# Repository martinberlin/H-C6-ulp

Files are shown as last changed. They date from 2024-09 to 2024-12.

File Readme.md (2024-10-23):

### ESP32-C6 ULP mini PCB

This PCB design is based on [C6 design guidelines](https://docs.espressif.com/projects/esp-hardware-design-guidelines/en/latest/esp32c6/schematic-checklist.html) and uses the Buck converter schematic of Seeed XIAO C6 [SGM6029](https://www.sg-micro.com/product/SGM6029)

> The SGM6029 family is a low voltage, efficient and miniature synchronous Buck converter with ultra-low quiescent current. Operating at high switching frequency (4.0MHz, TYP), miniature inductors and capacitors can be used to achieve minimal solution size.

#### Using low GPIOs to be able to access them from ULP

```
IO Description
0 EPD_MOSI
1 EPD_CLK
2 EPD_CS
3 EPD_DC
4 EPD_BSY
5 EPD_RST
6 SCL --> I2C ↘
7 SDA --> I2C connected to RV2032 RTC
```

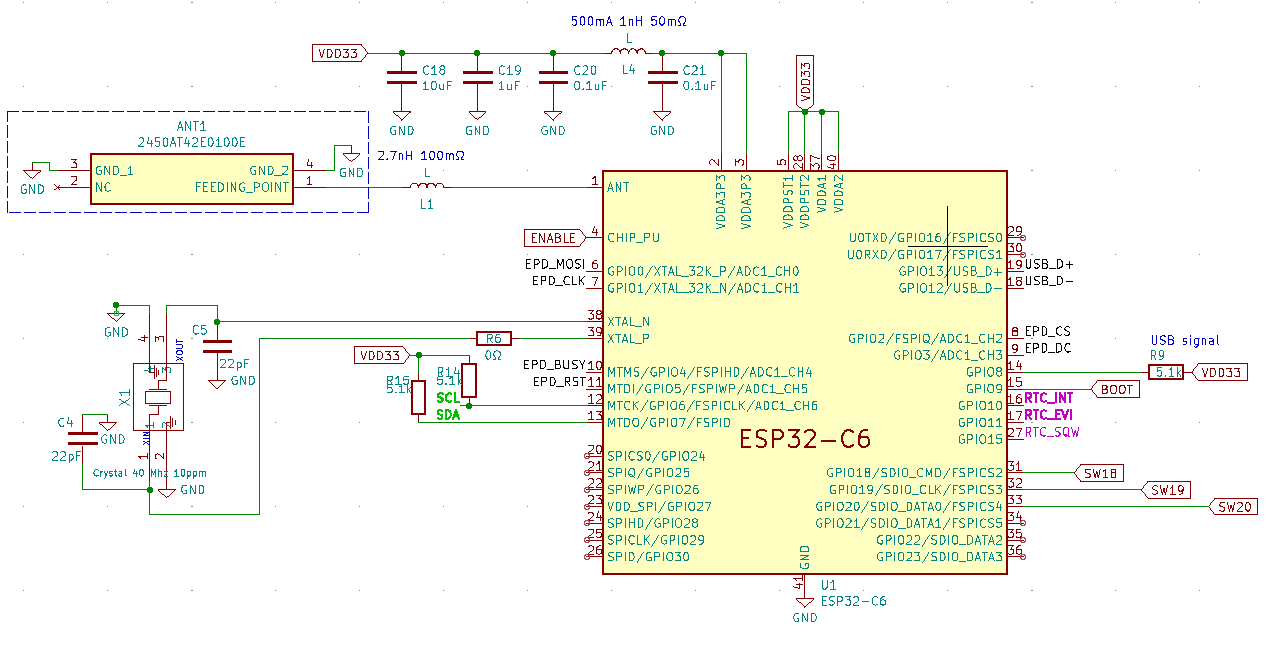
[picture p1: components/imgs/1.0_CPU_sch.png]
CPU schematic


### Push buttons GPIOs (optional side switches)

```
IO Description
19 Left  SW1 
20 Right SW2
18 Right SW3
```

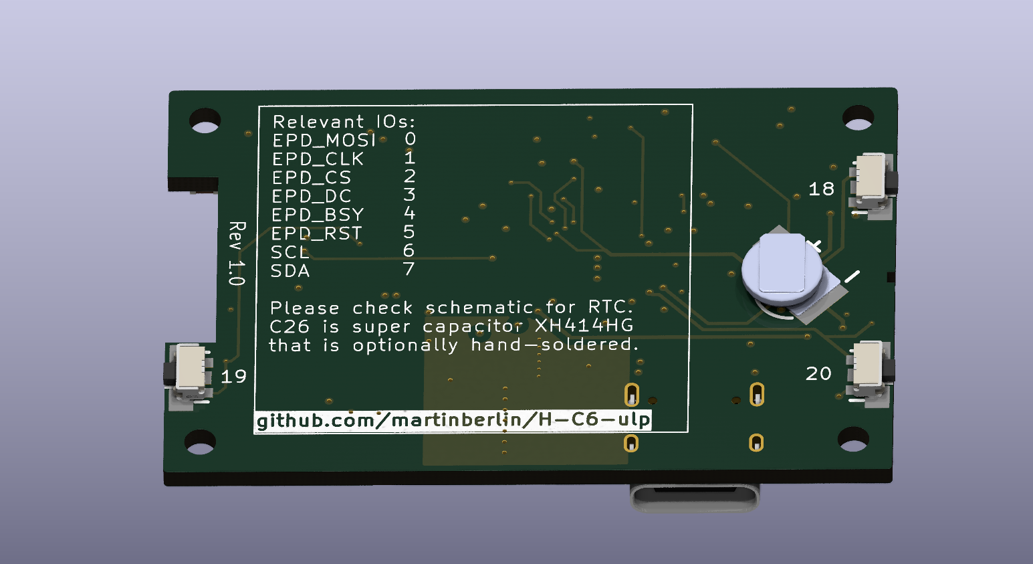
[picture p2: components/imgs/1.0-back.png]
SW placement


### 3D-Preview

Last version 1.1:

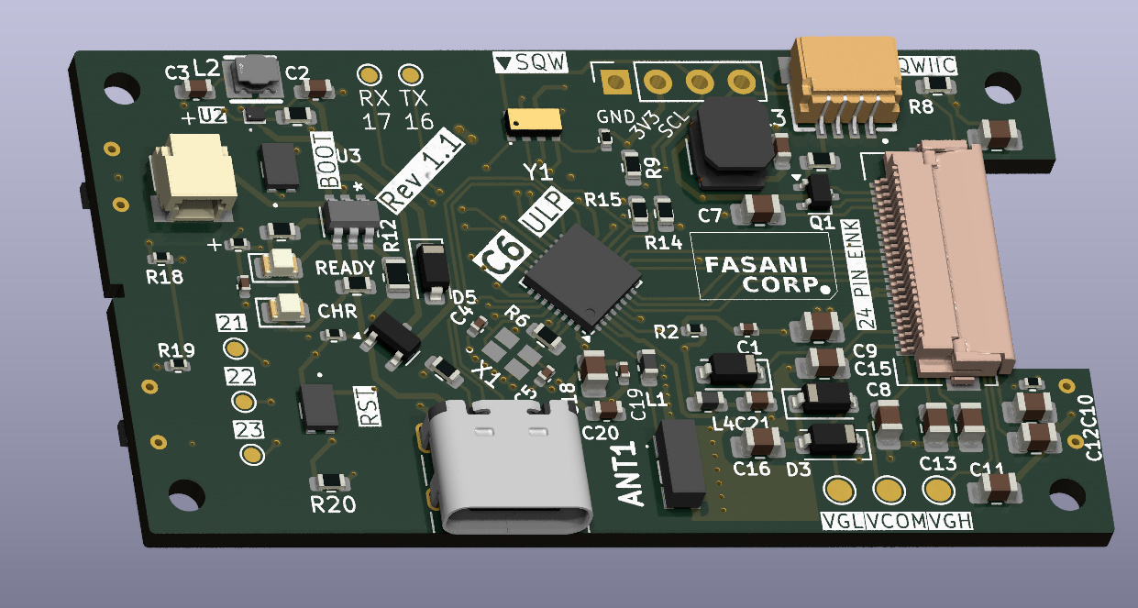
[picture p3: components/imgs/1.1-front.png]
Front PCB preview


Failed release v1.0: We forgot to add SPI flash. Oh yeah, you won't flash it!
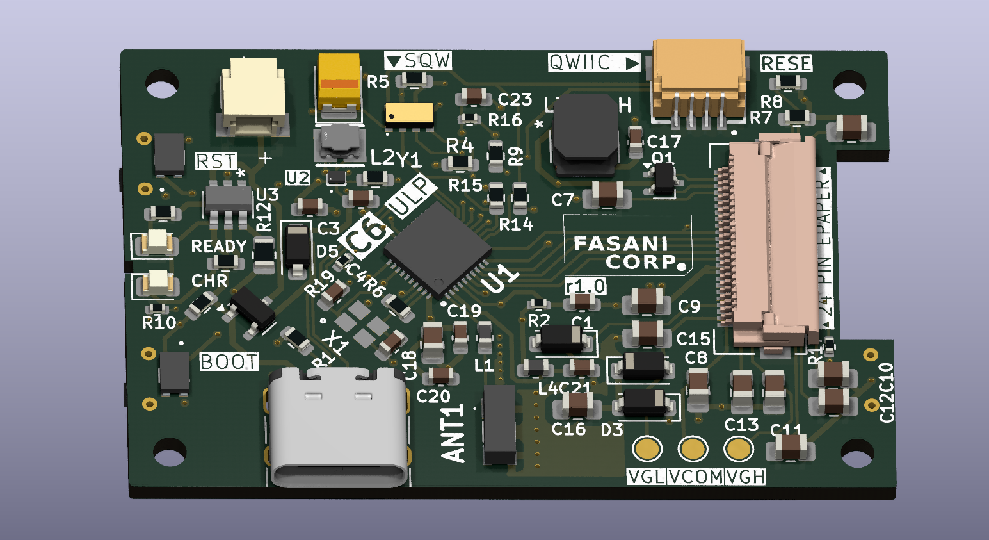
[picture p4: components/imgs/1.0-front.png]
Front PCB preview


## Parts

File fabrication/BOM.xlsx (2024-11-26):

Designator | Footprint | Comment | JLCPCB Part #
C14,C11,C6,C7,C15,C13 | C_0805_2012Metric_Pad1.18x1.45mm_HandSolder | 4.7uF | C1779
D5 | D_SOD-123 | 1N5817 | C8598
R17,R2,R18,R19,R16,R7,R4,R10 | R_0402_1005Metric | 10k | C25804
C1,C19 | C_0402_1005Metric | 1uF | C162161
C2,C3 | C_0603_1608Metric | 10 uF | C6119874
C5,C23,C4 | C_0402_1005Metric | 22pF | C5119318
R6 | R_0603_1608Metric | 0Ω | C21189
D2,D1,D3 | D_SOD-123 | MBR0530 | C77336
U3 | TP4057-42-SOT26-R | TP4057-42-SOT26-R | C12044
L2 | IND-SMD_L2.5-W2.0_SPH252012 | 0.47 uH | C329586
L3 | SWPA4030S1R0NT | 10uH | C38117
C8,C9,C10,C12 | C_0805_2012Metric_Pad1.18x1.45mm_HandSolder | 1uF | C28323
J3 | SM02BSRSSTBLFSN | SM02B-SRSS-TB(LF)(SN) | C160402
L1,L4 | L_0603_1608Metric | L | C5252358
R15,R20,R14,R13,R1,R9,R11 | R_0603_1608Metric | 5.1k | C23186
C20,C21 | C_0603_1608Metric | 0.1uF | C327087
SW2,SW1 | switch_SKSVCCE010 | SW_Push_Dual | C325005
C16 | C_0805_2012Metric_Pad1.18x1.45mm_HandSolder | 4.7uF 50V | C1779
C18 | C_0805_2012Metric | 10uF | C15850
C17 | C_0603_1608Metric | 4.7uF | C19666
R3 | R_0603_1608Metric | 249k 1% | C6945215
X1 | Crystal_ECS-40Mhz_ECS | Crystal 40 Mhz 10ppm | C555614
R12 | R_0805_2012Metric | 2K2 | C17520
J1 | USB_C_Receptacle_HRO_TYPE-C-31-M-12 | USB_C_Receptacle_USB2.0 | C165948
ANT1 | 2450AT42E0100E-ANT | 2450AT42E0100E | C3285081
Y1 | RV3032C7 | RV-3032-C7 | C5127802
D6 | LED_0805_2012Metric | GRE | C2297
J2 | AFC24-S24FIC-00 | AFC24-S24FIC-00 | C262292
R8 | R_0603_1608Metric | 0.47R | C103895
U2 | SGM6029_WLCSP-6 | SGM6029CYG/TR | C5153500
Q2 | SOT-23 | Si2301CDS | C10487
U1 | QFN-32-1EP_5x5mm_P0.5mm_EP3.6x3.6mm | ESP32-C6FH4 | C6908287
Q1 | SOT-323_SC-70 | Si1308 | C4322213
D4 | LED_0805_2012Metric | RED | C84256
J4 | QWIIC_SM04B-SRSS-TB_LFSN_ | SM04B-SRSS-TB_LF__SN_ | C160404

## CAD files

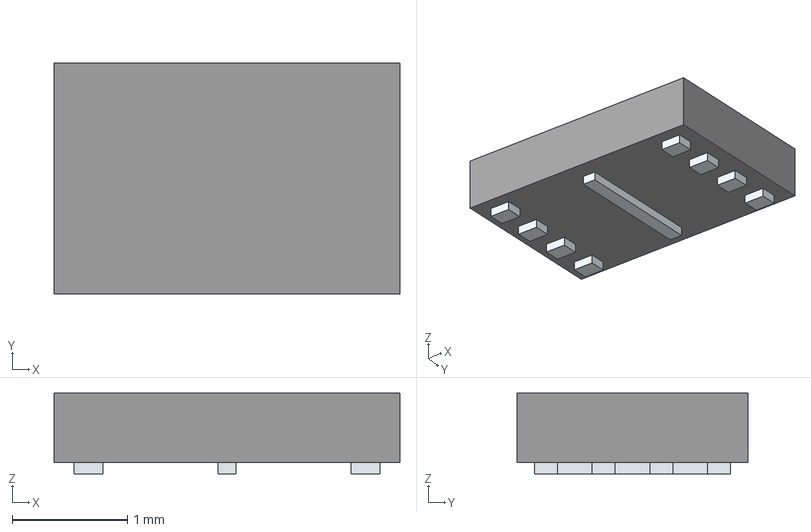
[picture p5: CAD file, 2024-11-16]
C6-40-Flash-test/components/3d/MX25R1635FZUIL0_TR_Flash.stp
3.00 x 2.00 x 0.7 mm
Pins

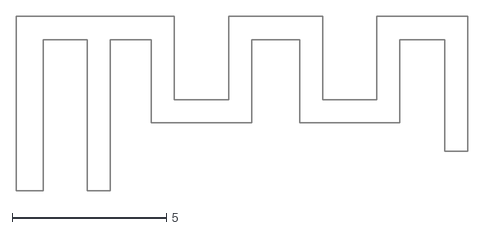
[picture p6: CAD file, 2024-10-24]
C6-40-Flash-test/components/ANTENNA - MIFA_TYPEB.dxf
14.6 x 5.65

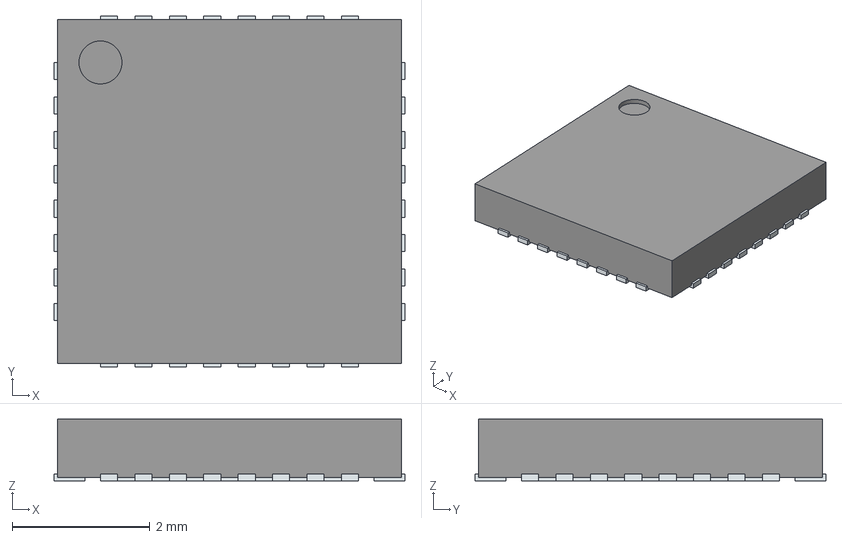
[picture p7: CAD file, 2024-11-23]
components/3D/ESP32-C6FH4.stp
5.10 x 5.10 x 0.9 mm
ThermalPin
PinsArrayLR
PinsArrayTB

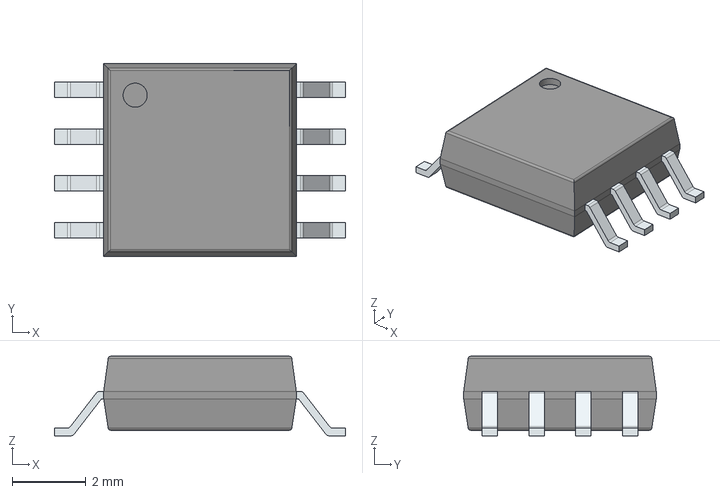
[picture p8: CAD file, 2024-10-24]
C6-40-Flash-test/components/3d/W25Q128JVSIQ-winbond-flash.stp
7.90 x 5.23 x 2.16 mm
PinsArrayLR

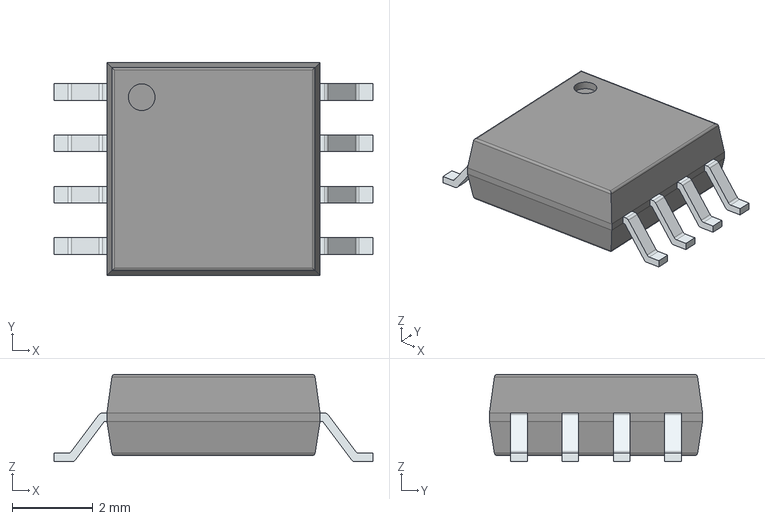
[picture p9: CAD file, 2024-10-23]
components/3D/W25Q80DVSSIG_FLASH.stp
7.90 x 5.28 x 2.16 mm
PinsArrayLR

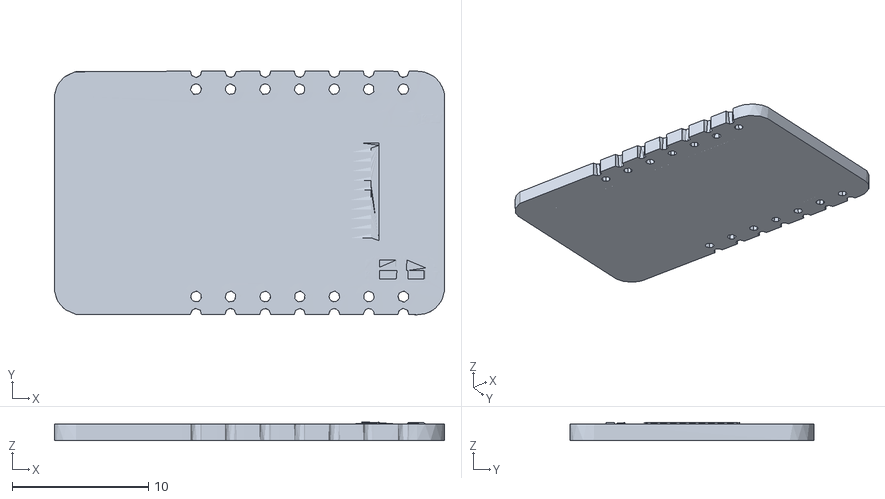
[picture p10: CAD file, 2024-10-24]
C6-40-Flash-test/components/3d/xiao-clean.stl
28.7 x 17.9 x 1.33

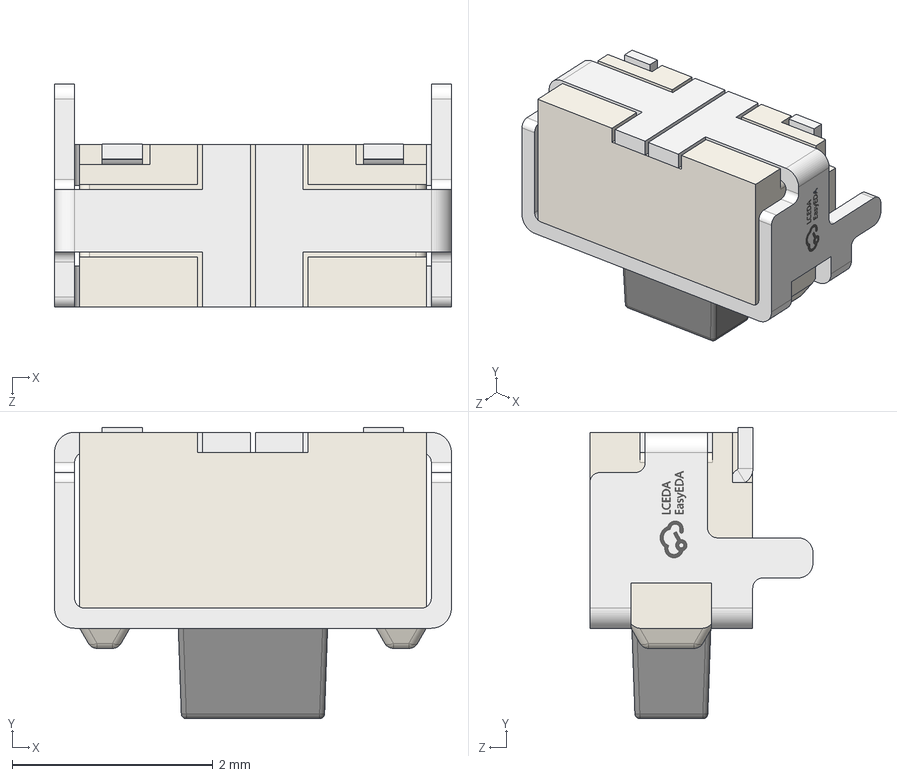
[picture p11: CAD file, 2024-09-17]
components/3D/KEY-SMD_L4.0-W2.9-H1.6-P3.75.step
3.95 x 2.90 x 2.22 mm

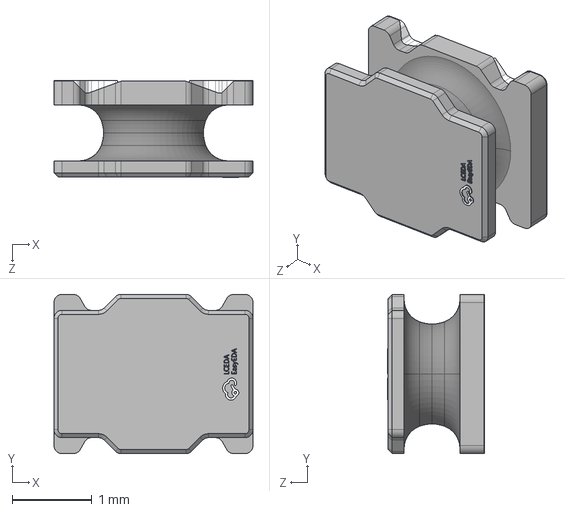
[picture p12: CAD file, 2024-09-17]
components/3D/IND-SMD_L2.5-W2.0-H1.2_SPH252012.step
2.50 x 2.00 x 1.22 mm

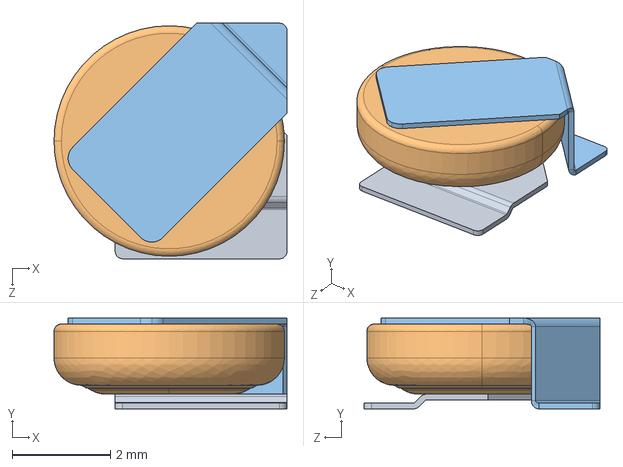
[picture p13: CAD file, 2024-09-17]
components/3D/SuperCAP_XH414HG-IV01E.stp
4.75 x 1.85 x 4.80 mm

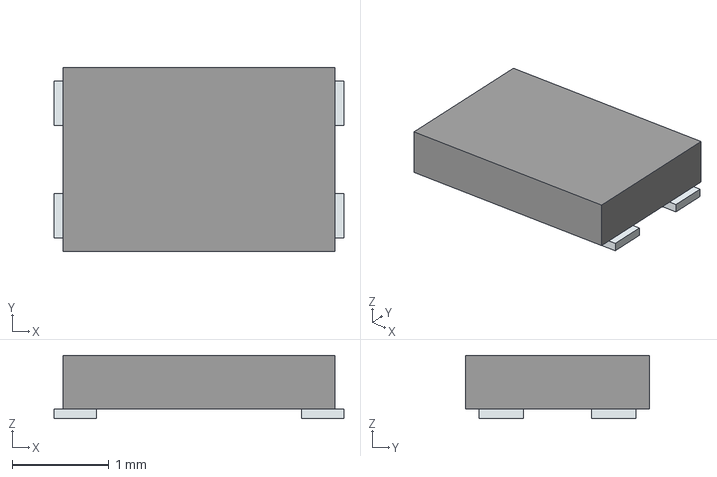
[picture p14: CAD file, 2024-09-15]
components/3D/switch_SKSVCCE010.stp
2.99 x 1.90 x 0.65 mm
Pins

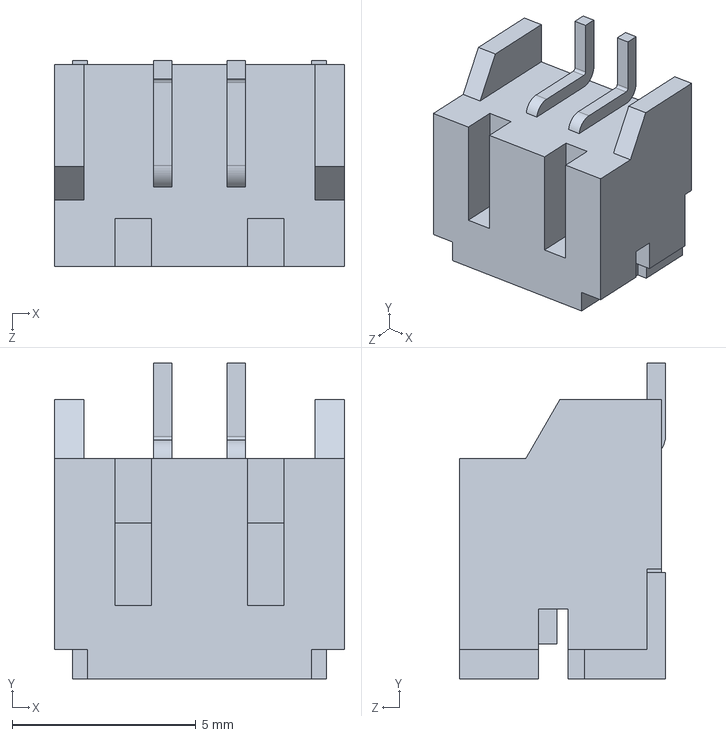
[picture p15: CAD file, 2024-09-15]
components/3D/S2B-PH-SM4-TB_LF__SN_.stp
7.90 x 8.60 x 5.60 mm

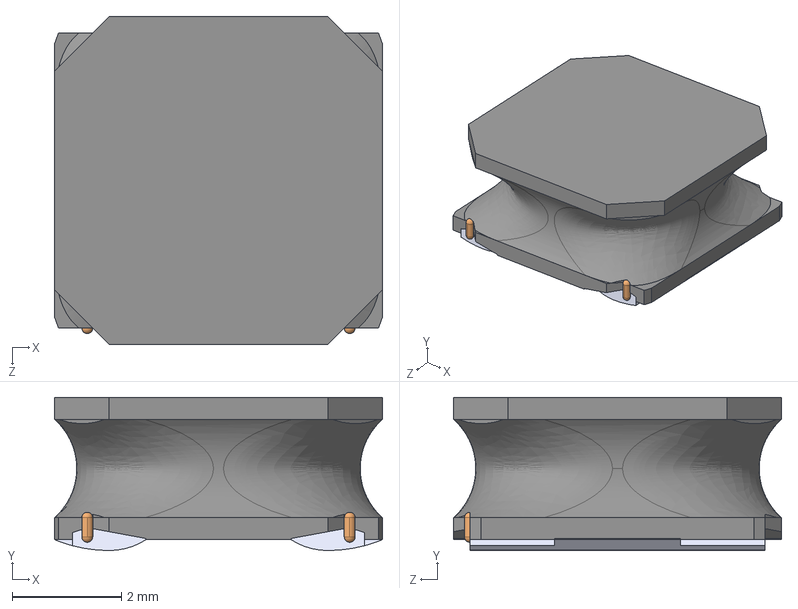
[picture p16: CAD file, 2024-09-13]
components/3D/L-40xx.stp
6.00 x 2.80 x 6.00 mm

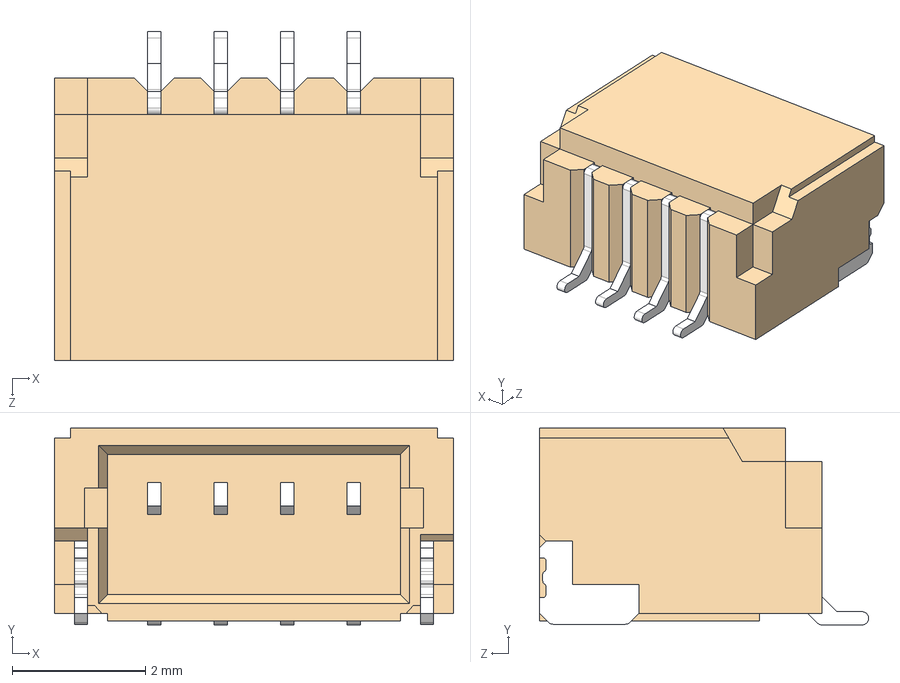
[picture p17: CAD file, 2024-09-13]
components/3D/QWIIC_SM04B-SRSS-TB_LF__SN_.stp
6.00 x 2.96 x 4.95 mm

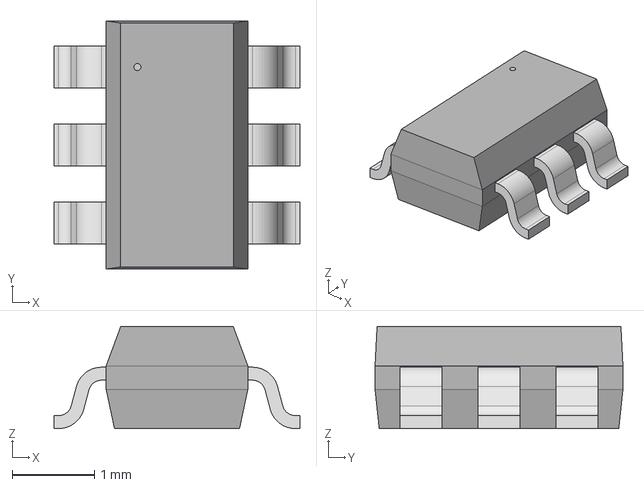
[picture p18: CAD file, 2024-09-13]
components/3D/TP4057-SOT-23.step
3.00 x 3.02 x 1.25 mm

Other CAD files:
components/3D/JST_SM02B-SRSS-TB__LF__SN.stp
components/3D/RV-3032-C7.stp
components/3D/FH12-24S-0.5SH_55_.step
components/3D/2450AT42E0100E-ANT.stp
components/3D/Crytal_ECS-40Mhz_ECS.step
components/3D/ESP32-C6.stp
components/3D/SGM6029_WLCSP-6_L1.0-W0.7.step
components/3D/USB_TYPE-C-31-M-12.step

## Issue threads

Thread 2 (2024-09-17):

PCB sharp Corners in layout

Uspizig, 2024-09-17:
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
Please avoid such sharp edges in PCB. This will result in underfill.

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

martinberlin, 2024-09-17:
Spider legs now look nicer
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
If you like the PCB project and it works will send you one as a present

Closed 2024-09-17.

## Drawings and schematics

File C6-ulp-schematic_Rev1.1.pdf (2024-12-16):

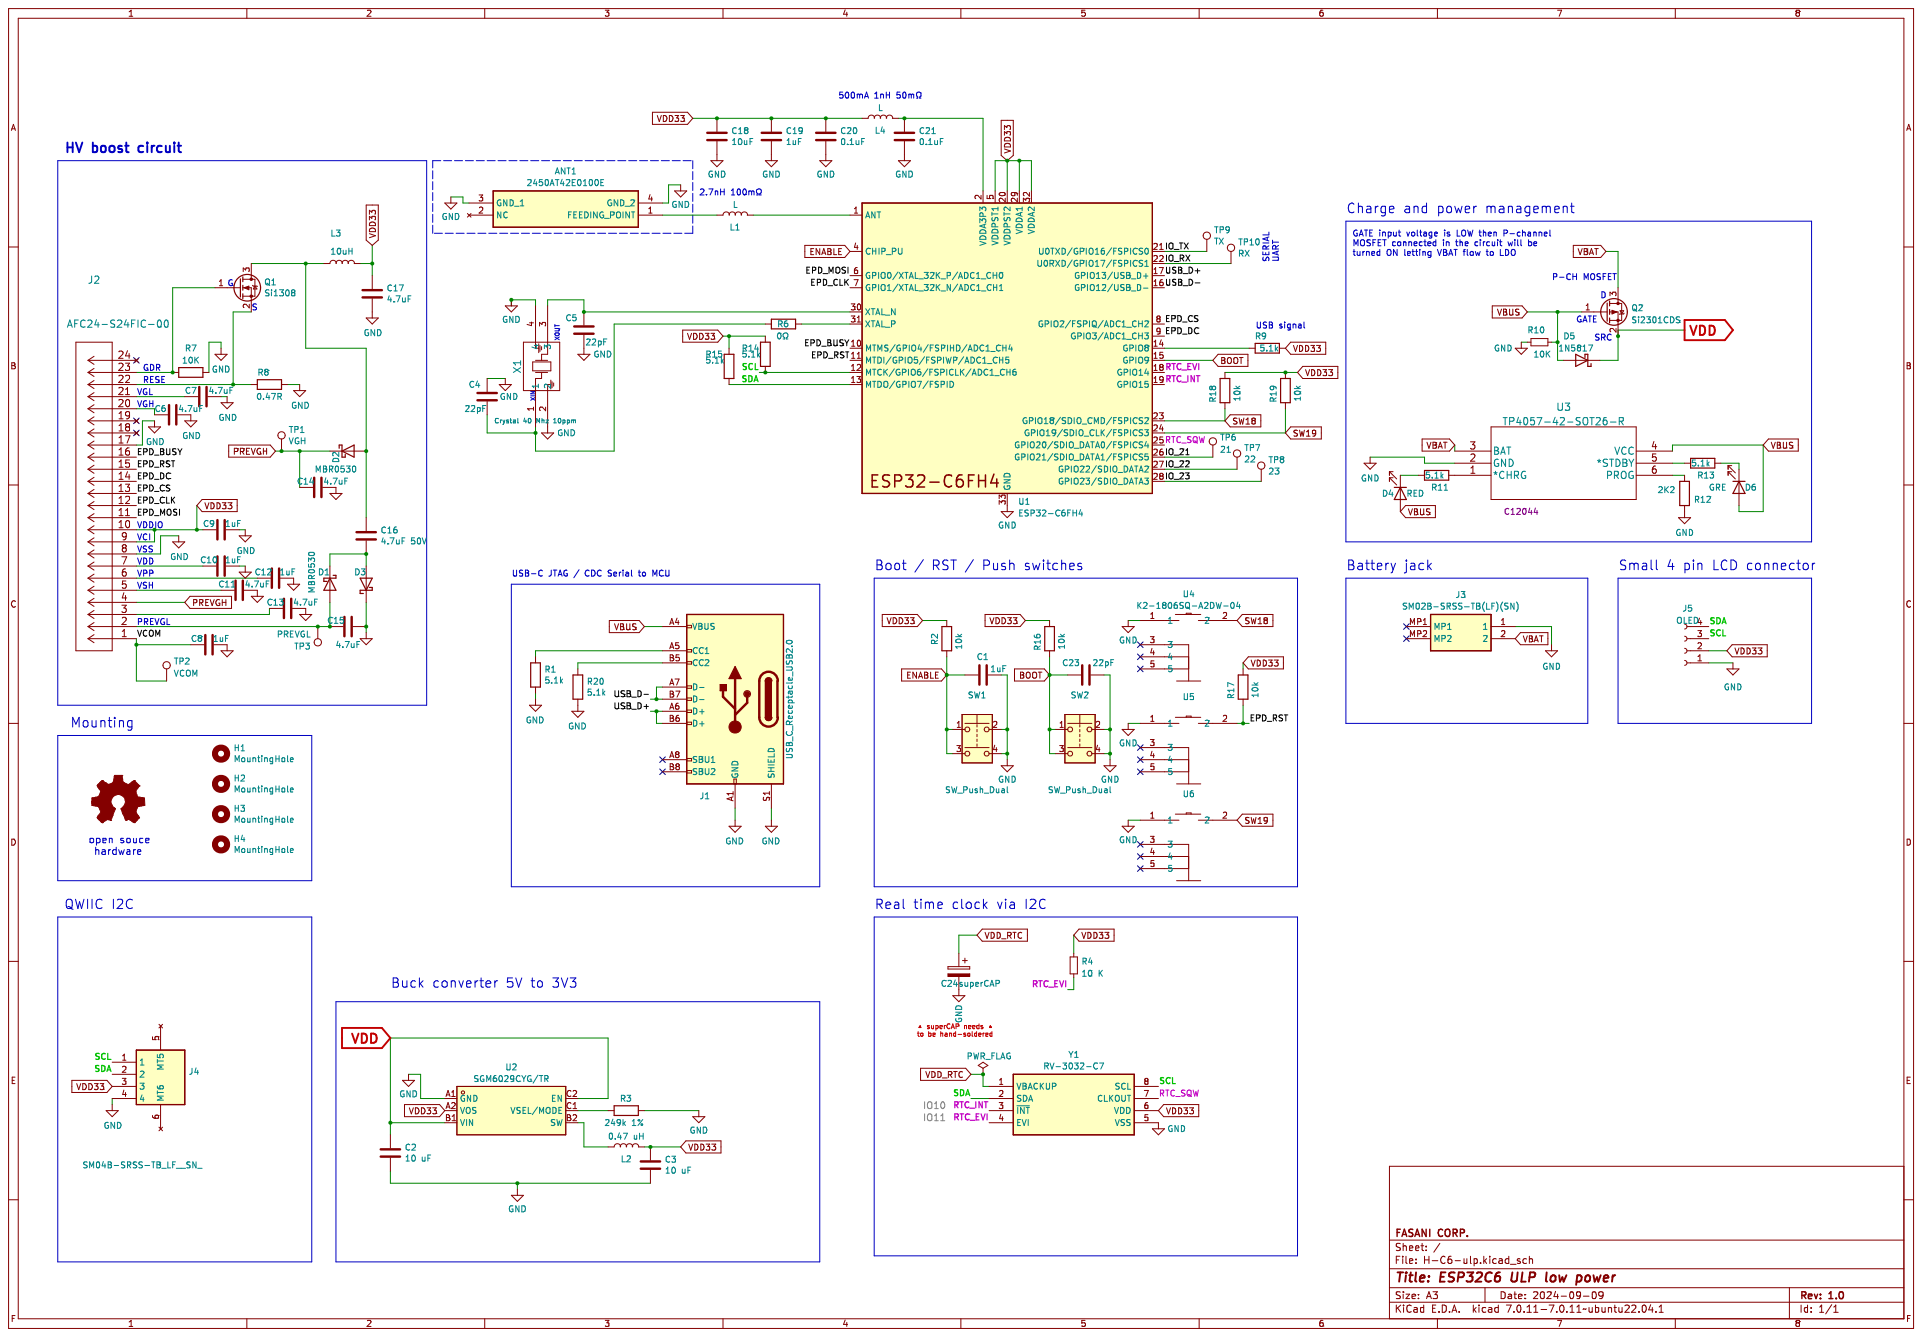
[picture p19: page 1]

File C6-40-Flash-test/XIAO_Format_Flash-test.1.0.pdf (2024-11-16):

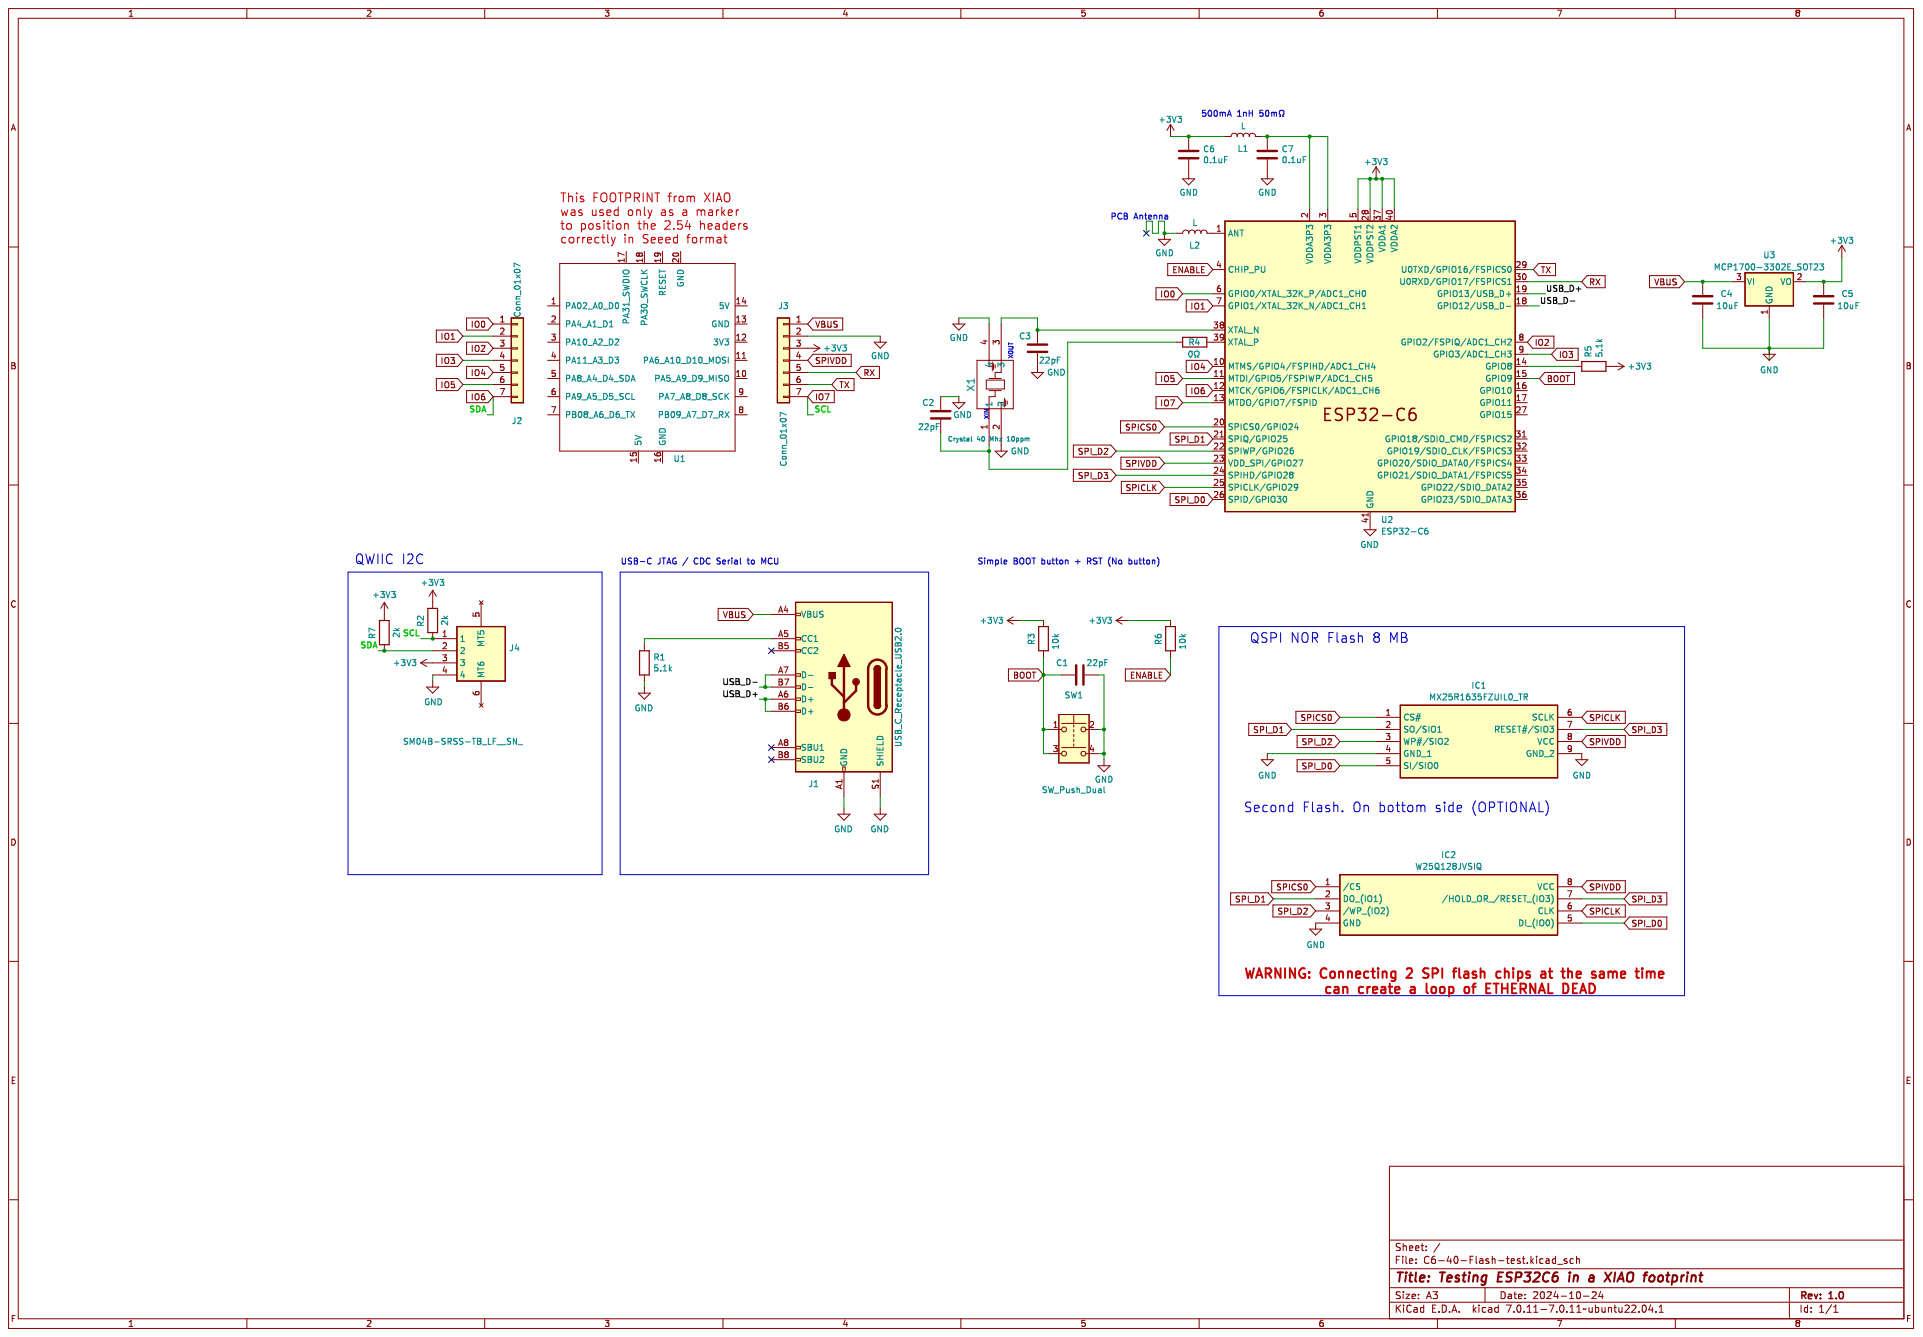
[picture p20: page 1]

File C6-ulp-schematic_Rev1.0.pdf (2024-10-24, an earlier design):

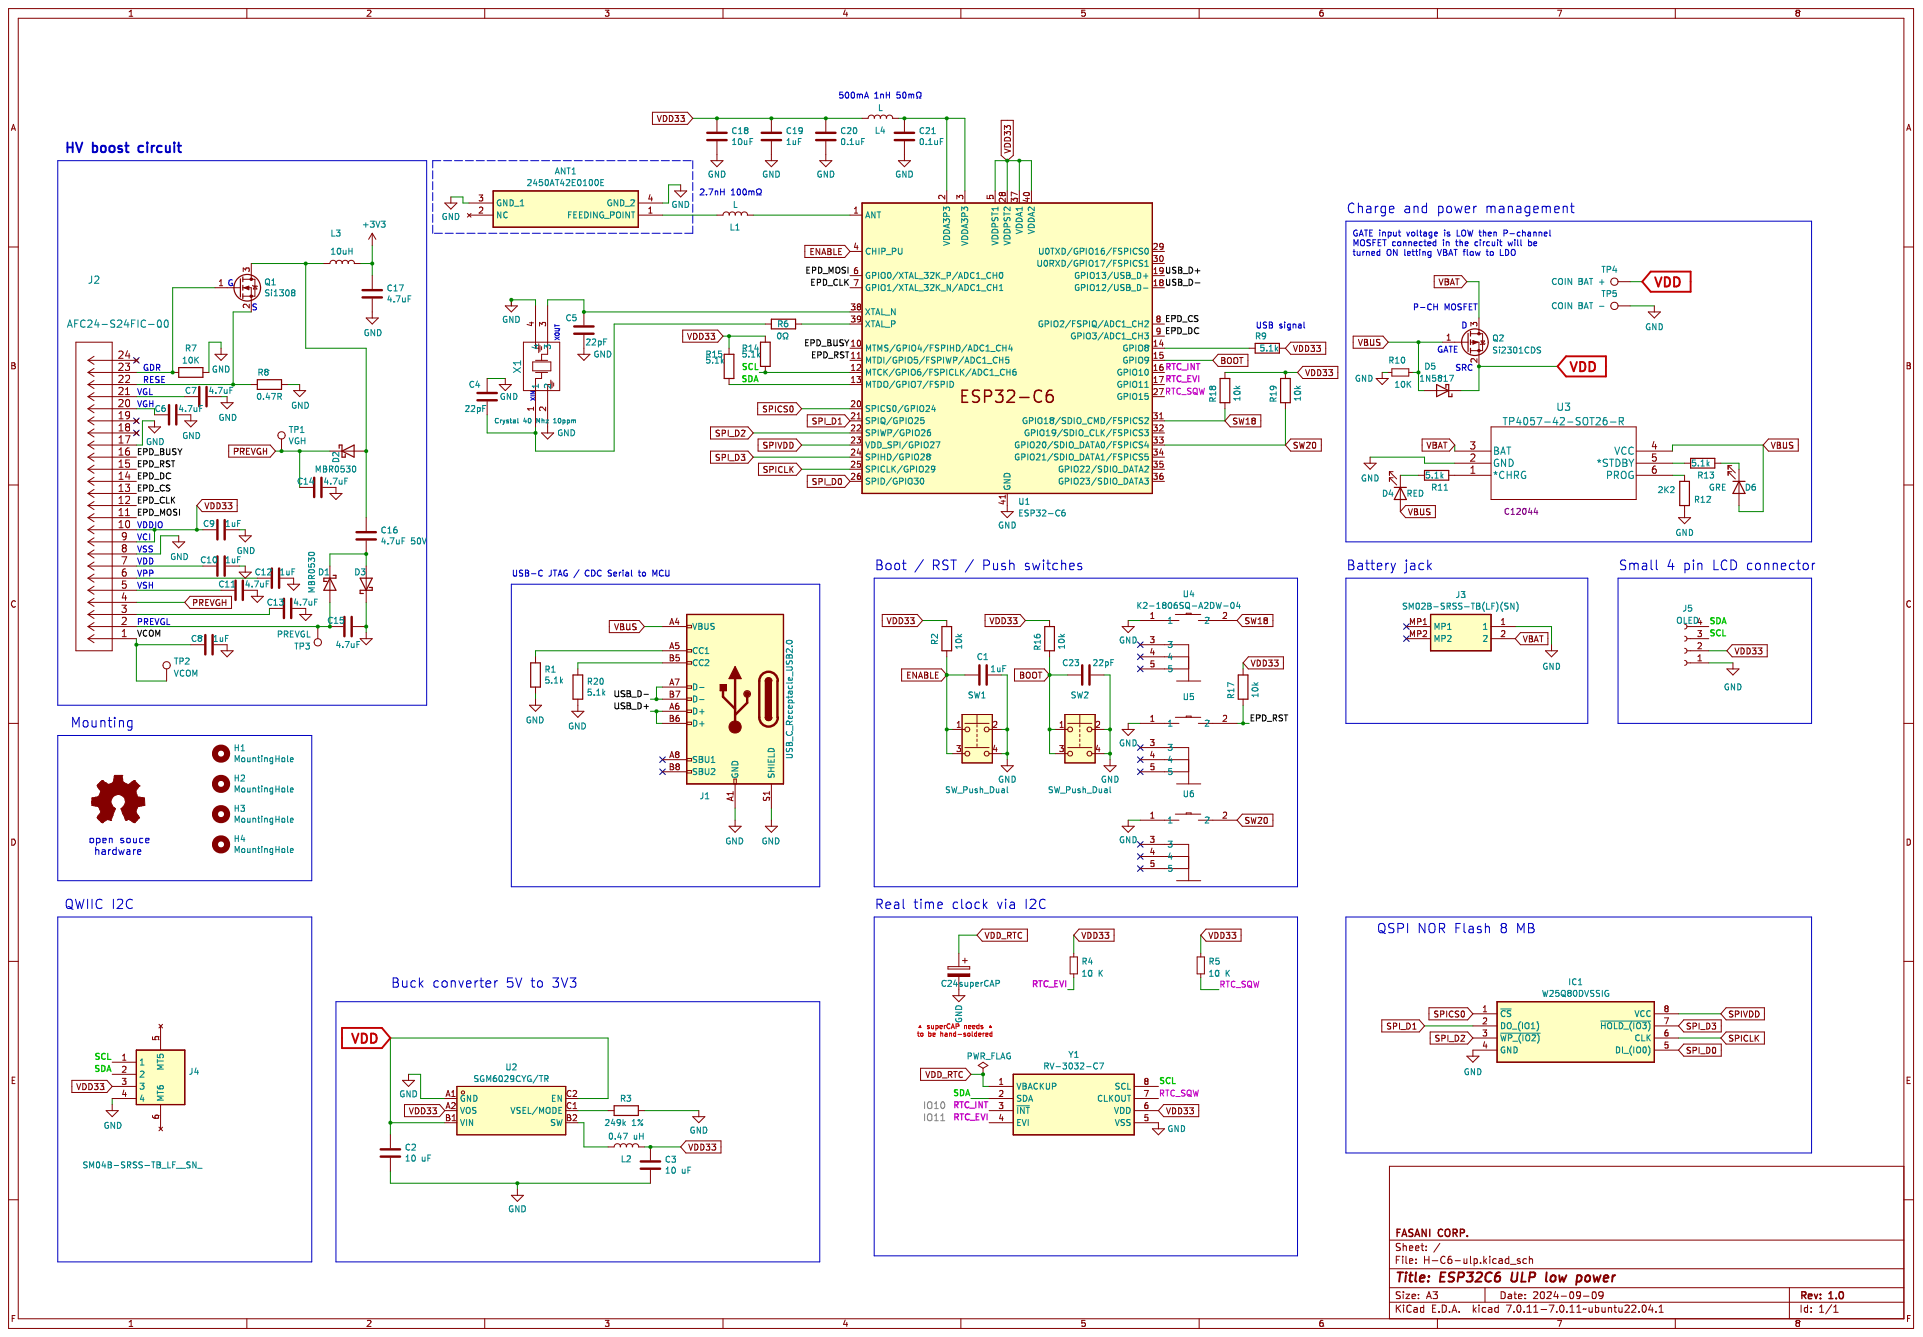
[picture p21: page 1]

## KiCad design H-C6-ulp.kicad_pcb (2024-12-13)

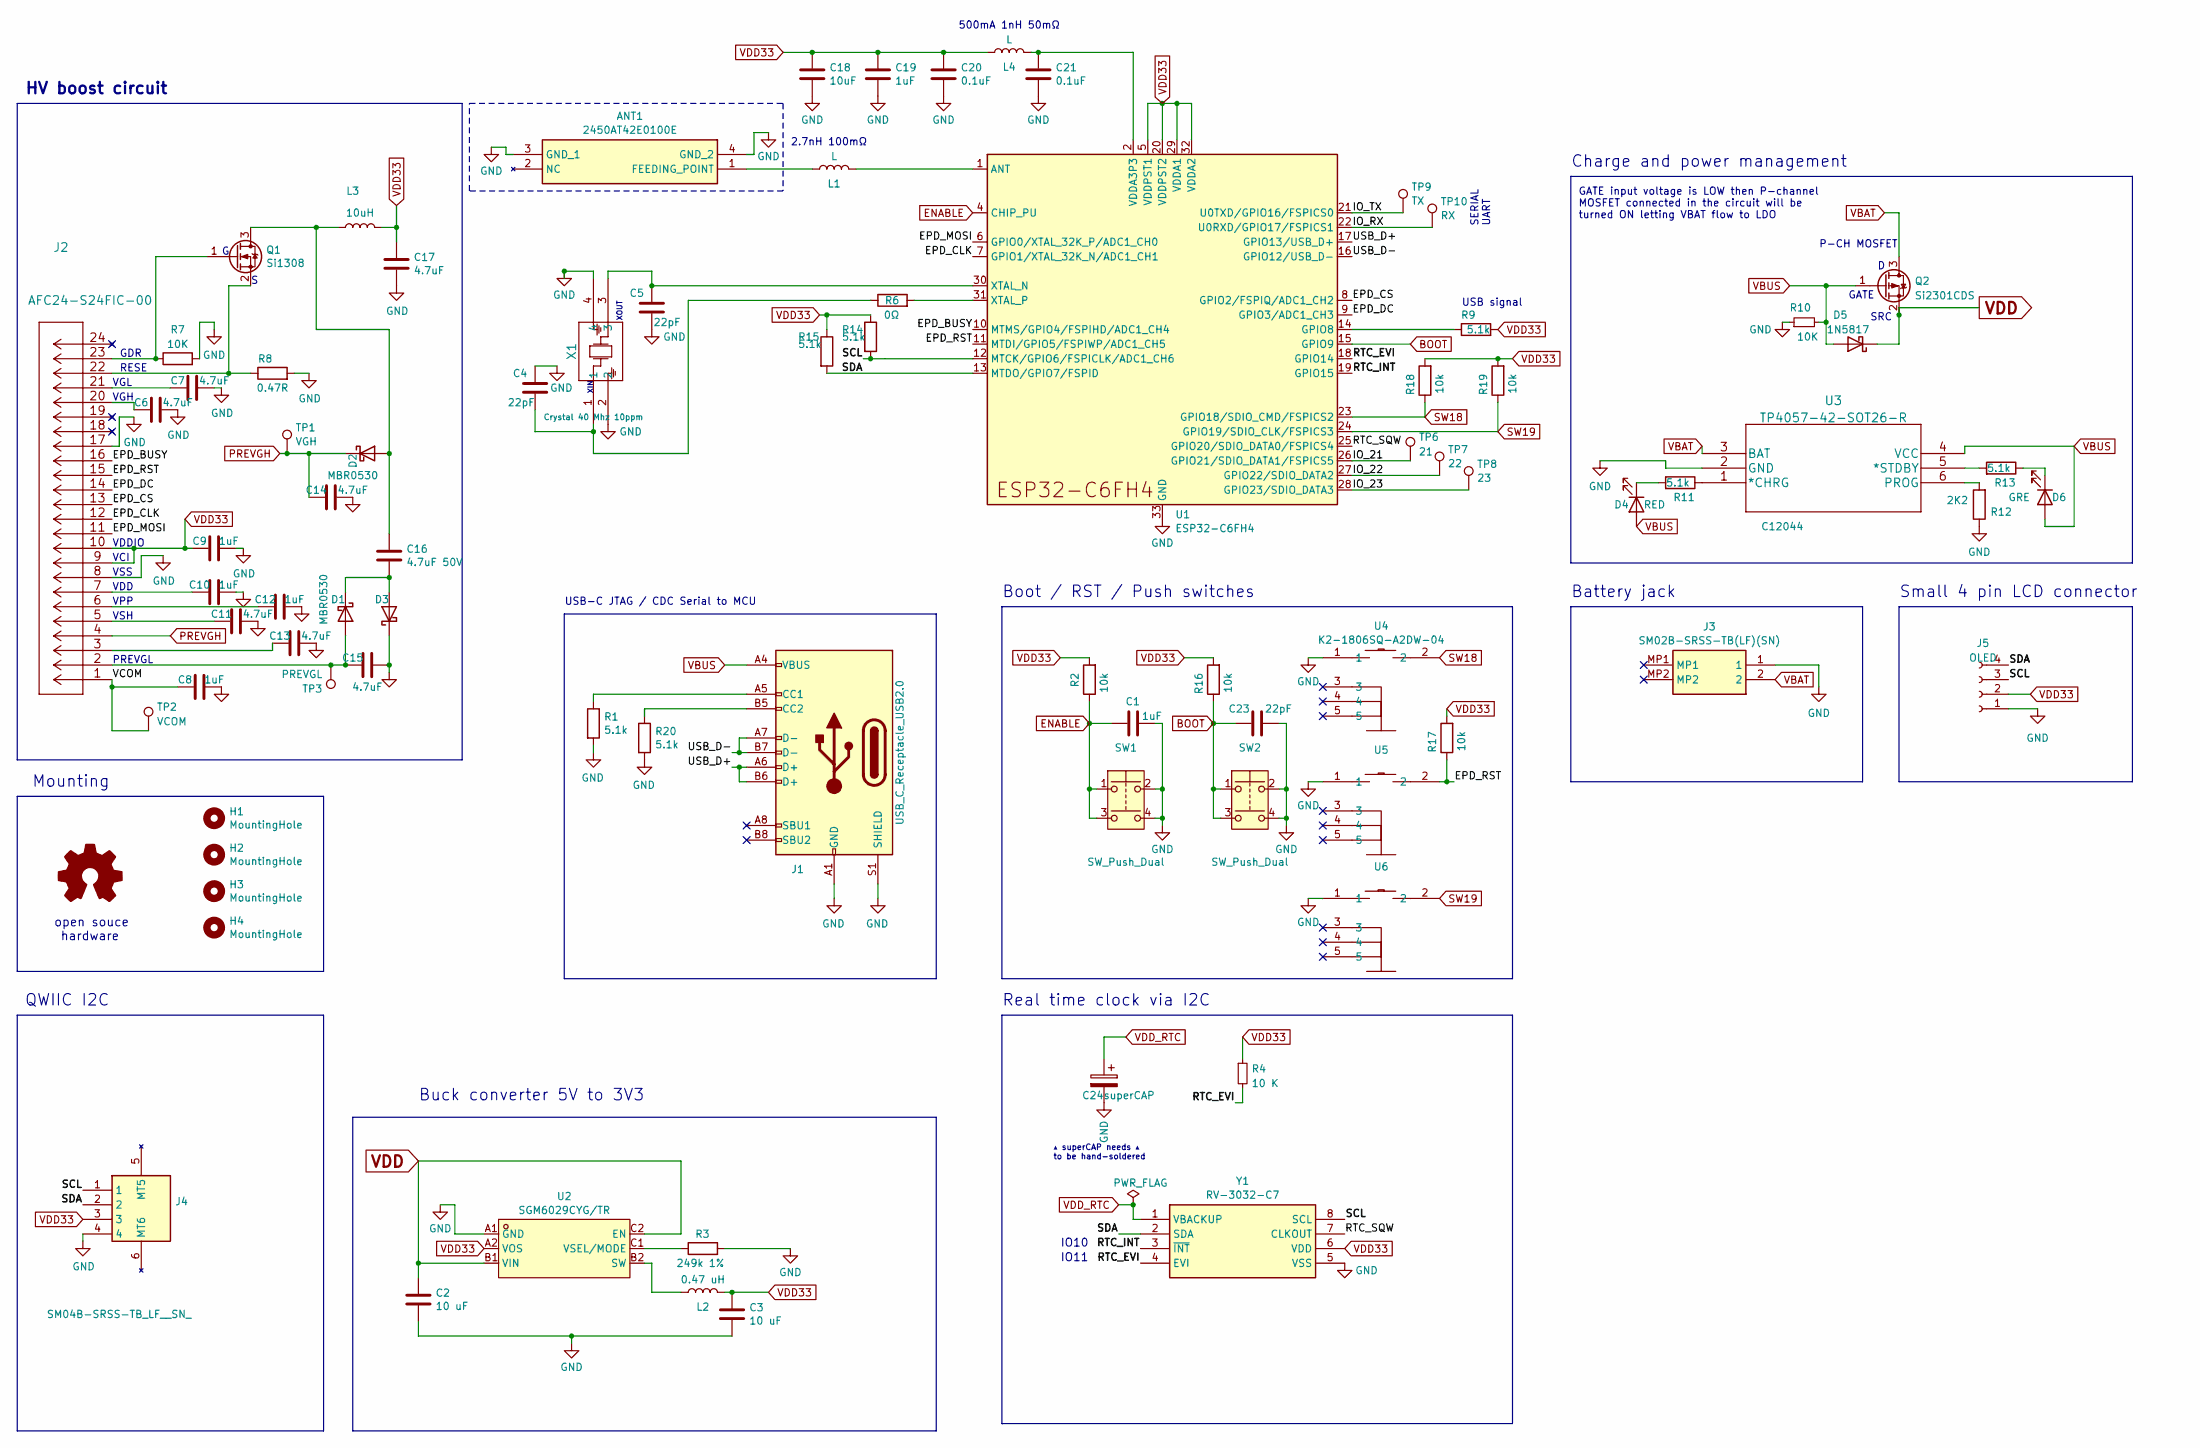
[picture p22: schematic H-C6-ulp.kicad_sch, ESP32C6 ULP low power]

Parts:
ANT1: 2450AT42E0100E; 2450AT42E0100E-ANT; LCSC C3285081
C1, C19: 1uF; C_0402_1005Metric; LCSC C162161
C2, C3: 10 uF; C_0603_1608Metric; LCSC C6119874
C4, C5, C23: 22pF; C_0402_1005Metric; LCSC C5119318
C6, C7, C11, C13, C14, C15: 4.7uF; C_0805_2012Metric_Pad1.18x1.45mm_HandSolder; LCSC C1779
C8, C9, C10, C12: 1uF; C_0805_2012Metric_Pad1.18x1.45mm_HandSolder; LCSC C28323
C16: 4.7uF 50V; C_0805_2012Metric_Pad1.18x1.45mm_HandSolder; LCSC C1779
C17: 4.7uF; C_0603_1608Metric; LCSC C19666
C18: 10uF; C_0805_2012Metric; LCSC C15850
C20, C21: 0.1uF; C_0603_1608Metric; LCSC C327087
C24: superCAP; superCAP-XH414HG; LCSC C129289
D1, D2, D3: MBR0530; D_SOD-123; LCSC C77336
D4: RED; LED_0805_2012Metric; LCSC C84256
D5: 1N5817; D_SOD-123; LCSC C8598
D6: GRE; LED_0805_2012Metric; LCSC C2297
H1, H2, H3, H4: MountingHole; MountingHole_2.2mm_M2
J1: USB_C_Receptacle_USB2.0; USB_C_Receptacle_HRO_TYPE-C-31-M-12; LCSC C165948
J2: AFC24-S24FIC-00; LCSC C262292
J3: SM02B-SRSS-TB(LF)(SN); SM02BSRSSTBLFSN; Manufacturer_Part_Number SM02B-SRSS-TB(LF)(SN); LCSC C160402
J4: SM04B-SRSS-TB_LF__SN_; QWIIC_SM04B-SRSS-TB_LFSN_; Manufacturer_Part_Number SM04B-SRSS-TB(LF)(SN); LCSC C160404
J5: OLED; PinSocket_1x04_P2.54mm_Vertical
L1: L; L_0603_1608Metric; LCSC C5252358
L2: 0.47 uH; IND-SMD_L2.5-W2.0_SPH252012; LCSC C329586
L3: 10uH; SWPA4030S1R0NT; LCSC C38117
L4: L; L_0603_1608Metric; LCSC C1027
Q1: Si1308; SOT-323_SC-70; LCSC C469327
Q2: Si2301CDS; SOT-23; LCSC C10487
R1, R9, R11, R13, R14, R15, R20: 5.1k; R_0603_1608Metric; LCSC C23186
R2, R16, R17, R18, R19: 10k; R_0402_1005Metric; LCSC C4322213
R3: 249k 1%; R_0603_1608Metric; LCSC C6945215
R4: 10 K; R_0402_1005Metric; LCSC C4322213
R6: 0Ω; R_0603_1608Metric; LCSC C21189
R7: 10K; R_0402_1005Metric; LCSC C4322213
R8: 0.47R; R_0603_1608Metric; LCSC C103895
R10: 10K; R_0402_1005Metric; LCSC C25804
R12: 2K2; R_0805_2012Metric; LCSC C17520
SW1, SW2: SW_Push_Dual; switch_SKSVCCE010; LCSC C325005
TP1: VGH; TestPoint_Pad_D1.5mm
TP2: VCOM; TestPoint_Pad_D1.5mm
TP3: PREVGL; TestPoint_Pad_D1.5mm
TP6: 21; TestPoint_Pad_D1.0mm
TP7: 22; TestPoint_Pad_D1.0mm
TP8: 23; TestPoint_Pad_D1.0mm
TP9: TX; TestPoint_Pad_D1.0mm
TP10: RX; TestPoint_Pad_D1.0mm
U1: ESP32-C6FH4; QFN-32-1EP_5x5mm_P0.5mm_EP3.6x3.6mm; LCSC C6908287
U2: SGM6029CYG/TR; SGM6029_WLCSP-6; LCSC Part C5153500
U3: TP4057-42-SOT26-R; LCSC C12044
U4, U5, U6: K2-1806SQ-A2DW-04; KEY-SMD_K2-1806SQ-A3DW-04; LCSC Part C19100323
X1: Crystal 40 Mhz 10ppm; Crystal_ECS-40Mhz_ECS; LCSC C555614
Y1: RV-3032-C7; RV3032C7; LCSC C5127802

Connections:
/EPD_BUSY: J2.16, U1.10 (MTMS/GPIO4/FSPIHD/ADC1_CH4)
/EPD_CLK: J2.12, U1.7 (GPIO1/XTAL_32K_N/ADC1_CH1)
/EPD_CS: J2.13, U1.8 (GPIO2/FSPIQ/ADC1_CH2)
/EPD_DC: J2.14, U1.9 (GPIO3/ADC1_CH3)
/EPD_MOSI: J2.11, U1.6 (GPIO0/XTAL_32K_P/ADC1_CH0)
/EPD_RST: J2.15, R17.1, U1.11 (MTDI/GPIO5/FSPIWP/ADC1_CH5), U5.2
/IO_21: TP6.1, U1.26 (GPIO21/SDIO_DATA1/FSPICS5)
/IO_22: TP7.1, U1.27 (GPIO22/SDIO_DATA2)
/IO_23: TP8.1, U1.28 (GPIO23/SDIO_DATA3)
/IO_RX: TP10.1, U1.22 (U0RXD/GPIO17/FSPICS1)
/IO_TX: TP9.1, U1.21 (U0TXD/GPIO16/FSPICS0)
/RTC_EVI: R4.2, U1.18 (GPIO14), Y1.4 (EVI)
/RTC_INT: U1.19 (GPIO15), Y1.3 (~INT)
/RTC_SQW: U1.25 (GPIO20/SDIO_DATA0/FSPICS4), Y1.7 (CLKOUT)
/SCL: J4.1, J5.3, R14.2, U1.12 (MTCK/GPIO6/FSPICLK/ADC1_CH6), Y1.8 (SCL)
/SDA: J4.2, J5.4, R15.2, U1.13 (MTDO/GPIO7/FSPID), Y1.2 (SDA)
/USB_D+: J1.A6 (D+), J1.B6 (D+), U1.17 (GPIO13/USB_D+)
/USB_D-: J1.A7 (D-), J1.B7 (D-), U1.16 (GPIO12/USB_D-)
/VCOM: C8.2, J2.1, TP2.1
BOOT: C23.1, R16.1, SW2.1, SW2.3, U1.15 (GPIO9)
ENABLE: C1.2, R2.1, SW1.1, SW1.3, U1.4 (CHIP_PU)
GND: ANT1.3 (GND_1), ANT1.4 (GND_2), C1.1, C2.1, C3.1, C4.1, C5.2, C6.1, C7.1, C8.1, C9.1, C10.1, C11.1, C12.1, C13.1, C14.1, C15.1, C17.1, C18.1, C19.1, C20.1, C21.1, C23.2, C24.2, D3.1 (K), J1.A1 (GND), J1.A12 (GND), J1.B1 (GND), J1.B12 (GND), J1.S1 (SHIELD), J2.8, J2.17, J3.1, J4.4, J5.1, R1.2, R3.2, R7.2, R8.2, R10.1, R12.1, R20.2, SW1.2, SW1.4, SW2.2, SW2.4, U1.33 (GND), U2.A1 (GND), U3.2 (GND), U4.1, U5.1, U6.1, X1.2, X1.4, Y1.5 (VSS)
unnamed: ANT1.1 (FEEDING_POINT), L1.1
unnamed: C4.2, R6.1, X1.1
unnamed: C6.2, J2.20
unnamed: C7.2, J2.21
unnamed: C10.2, J2.7
unnamed: C11.2, J2.5
unnamed: C12.2, J2.6
unnamed: C13.2, J2.3
unnamed: C21.2, L4.2, U1.2 (VDDA3P3), U1.3 (VDDA3P3)
unnamed: C15.2, D1.2 (A), J2.2, TP3.1
unnamed: C16.1, D1.1 (K), D3.2 (A)
unnamed: C16.2, D2.2 (A), L3.1, Q1.3 (D)
unnamed: D4.1 (K), R11.2
unnamed: D6.1 (K), R13.1
unnamed: J1.A5 (CC1), R1.1
unnamed: J1.B5 (CC2), R20.1
unnamed: J2.23, Q1.1 (G), R7.1
unnamed: J2.22, Q1.2 (S), R8.1
unnamed: L1.2, U1.1 (ANT)
unnamed: R9.1, U1.14 (GPIO8)
unnamed: C5.1, U1.30 (XTAL_N), X1.3
unnamed: R6.2, U1.31 (XTAL_P)
unnamed: L2.1, U2.B2 (SW)
unnamed: R3.1, U2.C1 (VSEL/MODE)
unnamed: R11.1, U3.1 (*CHRG)
unnamed: R13.2, U3.5 (*STDBY)
unnamed: R12.2, U3.6 (PROG)
PREVGH: C14.2, D2.1 (K), J2.4, TP1.1
SW18: R18.1, U1.23 (GPIO18/SDIO_CMD/FSPICS2), U4.2
SW19: R19.1, U1.24 (GPIO19/SDIO_CLK/FSPICS3), U6.2
VBAT: J3.2, Q2.3 (D), U3.3 (BAT)
VBUS: D4.2 (A), D5.2 (A), D6.2 (A), J1.A4 (VBUS), J1.A9 (VBUS), J1.B4 (VBUS), J1.B9 (VBUS), Q2.1 (G), R10.2, U3.4 (VCC)
VDD: C2.2, D5.1 (K), Q2.2 (S), U2.B1 (VIN), U2.C2 (EN)
VDD33: C3.2, C9.2, C17.2, C18.2, C19.2, C20.2, J2.9, J2.10, J4.3, J5.2, L2.2, L3.2, L4.1, R2.2, R4.1, R9.2, R14.1, R15.1, R16.2, R17.2, R18.2, R19.2, U1.5 (VDDPST1), U1.20 (VDDPST2), U1.29 (VDDA1), U1.32 (VDDA2), U2.A2 (VOS), Y1.6 (VDD)
VDD_RTC: C24.1, Y1.1 (VBACKUP)

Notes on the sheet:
USB-C JTAG / CDC Serial to MCU
Mounting
IO10
VGH
RESE
VGL
HV boost circuit
Buck converter 5V to 3V3
XOUT
Real time clock via I2C
500mA 1nH 50mΩ
Small 4 pin LCD connector
VSH
VPP
QWIIC I2C
SRC
GATE
open souce hardware
GDR
P-CH MOSFET
Battery jack
▴ superCAP needs ▴ to be hand-soldered
IO11
Boot / RST / Push switches
VDDIO
GATE input voltage is LOW then P-channel MOSFET connected in the circuit will be turned ON letting VBAT flow to LDO
USB signal
PREVGL
XIN
2.7nH 100mΩ
VSS
VCI
Charge and power management
SERIAL UART
VDD

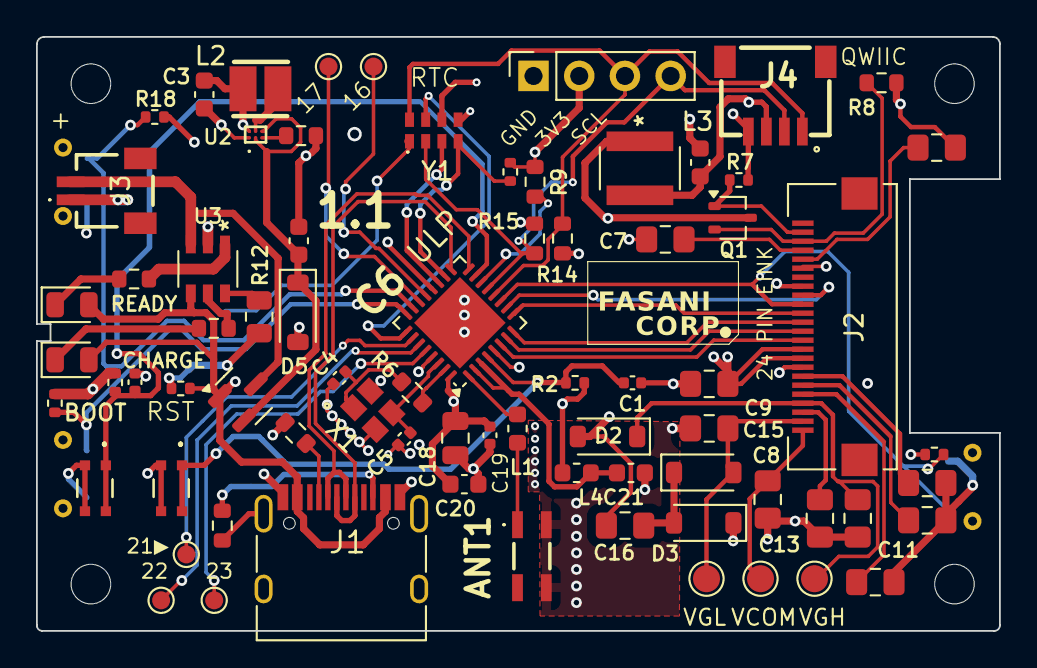
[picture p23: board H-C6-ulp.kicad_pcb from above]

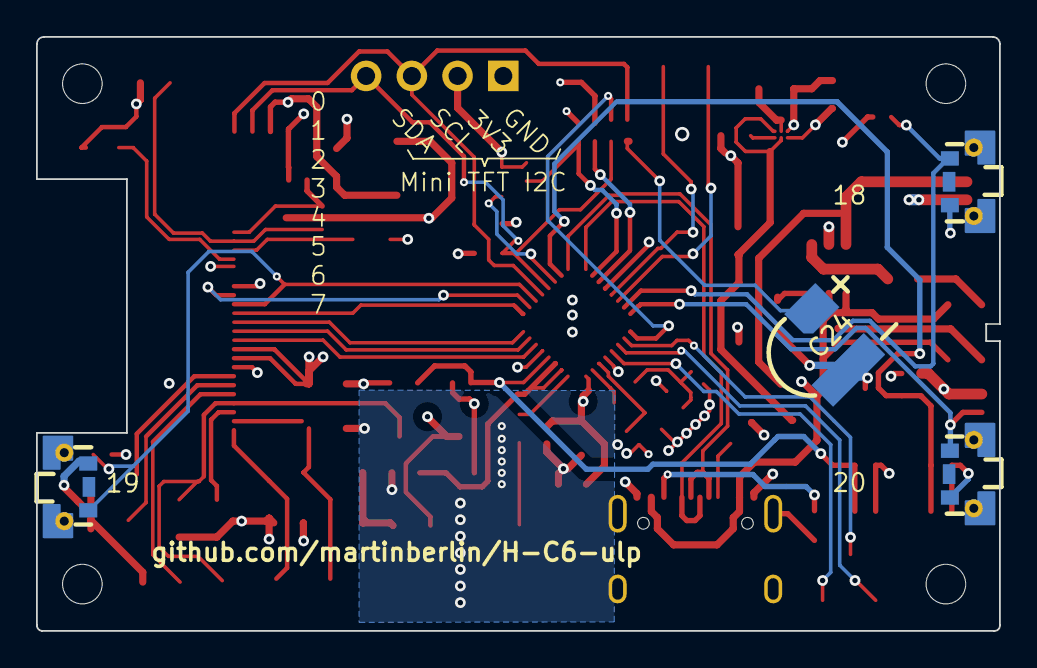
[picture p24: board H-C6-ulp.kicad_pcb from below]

Board: 4 copper layers, 53.5 x 33.0 mm, 82 parts (4 on the bottom side), 57 nets.

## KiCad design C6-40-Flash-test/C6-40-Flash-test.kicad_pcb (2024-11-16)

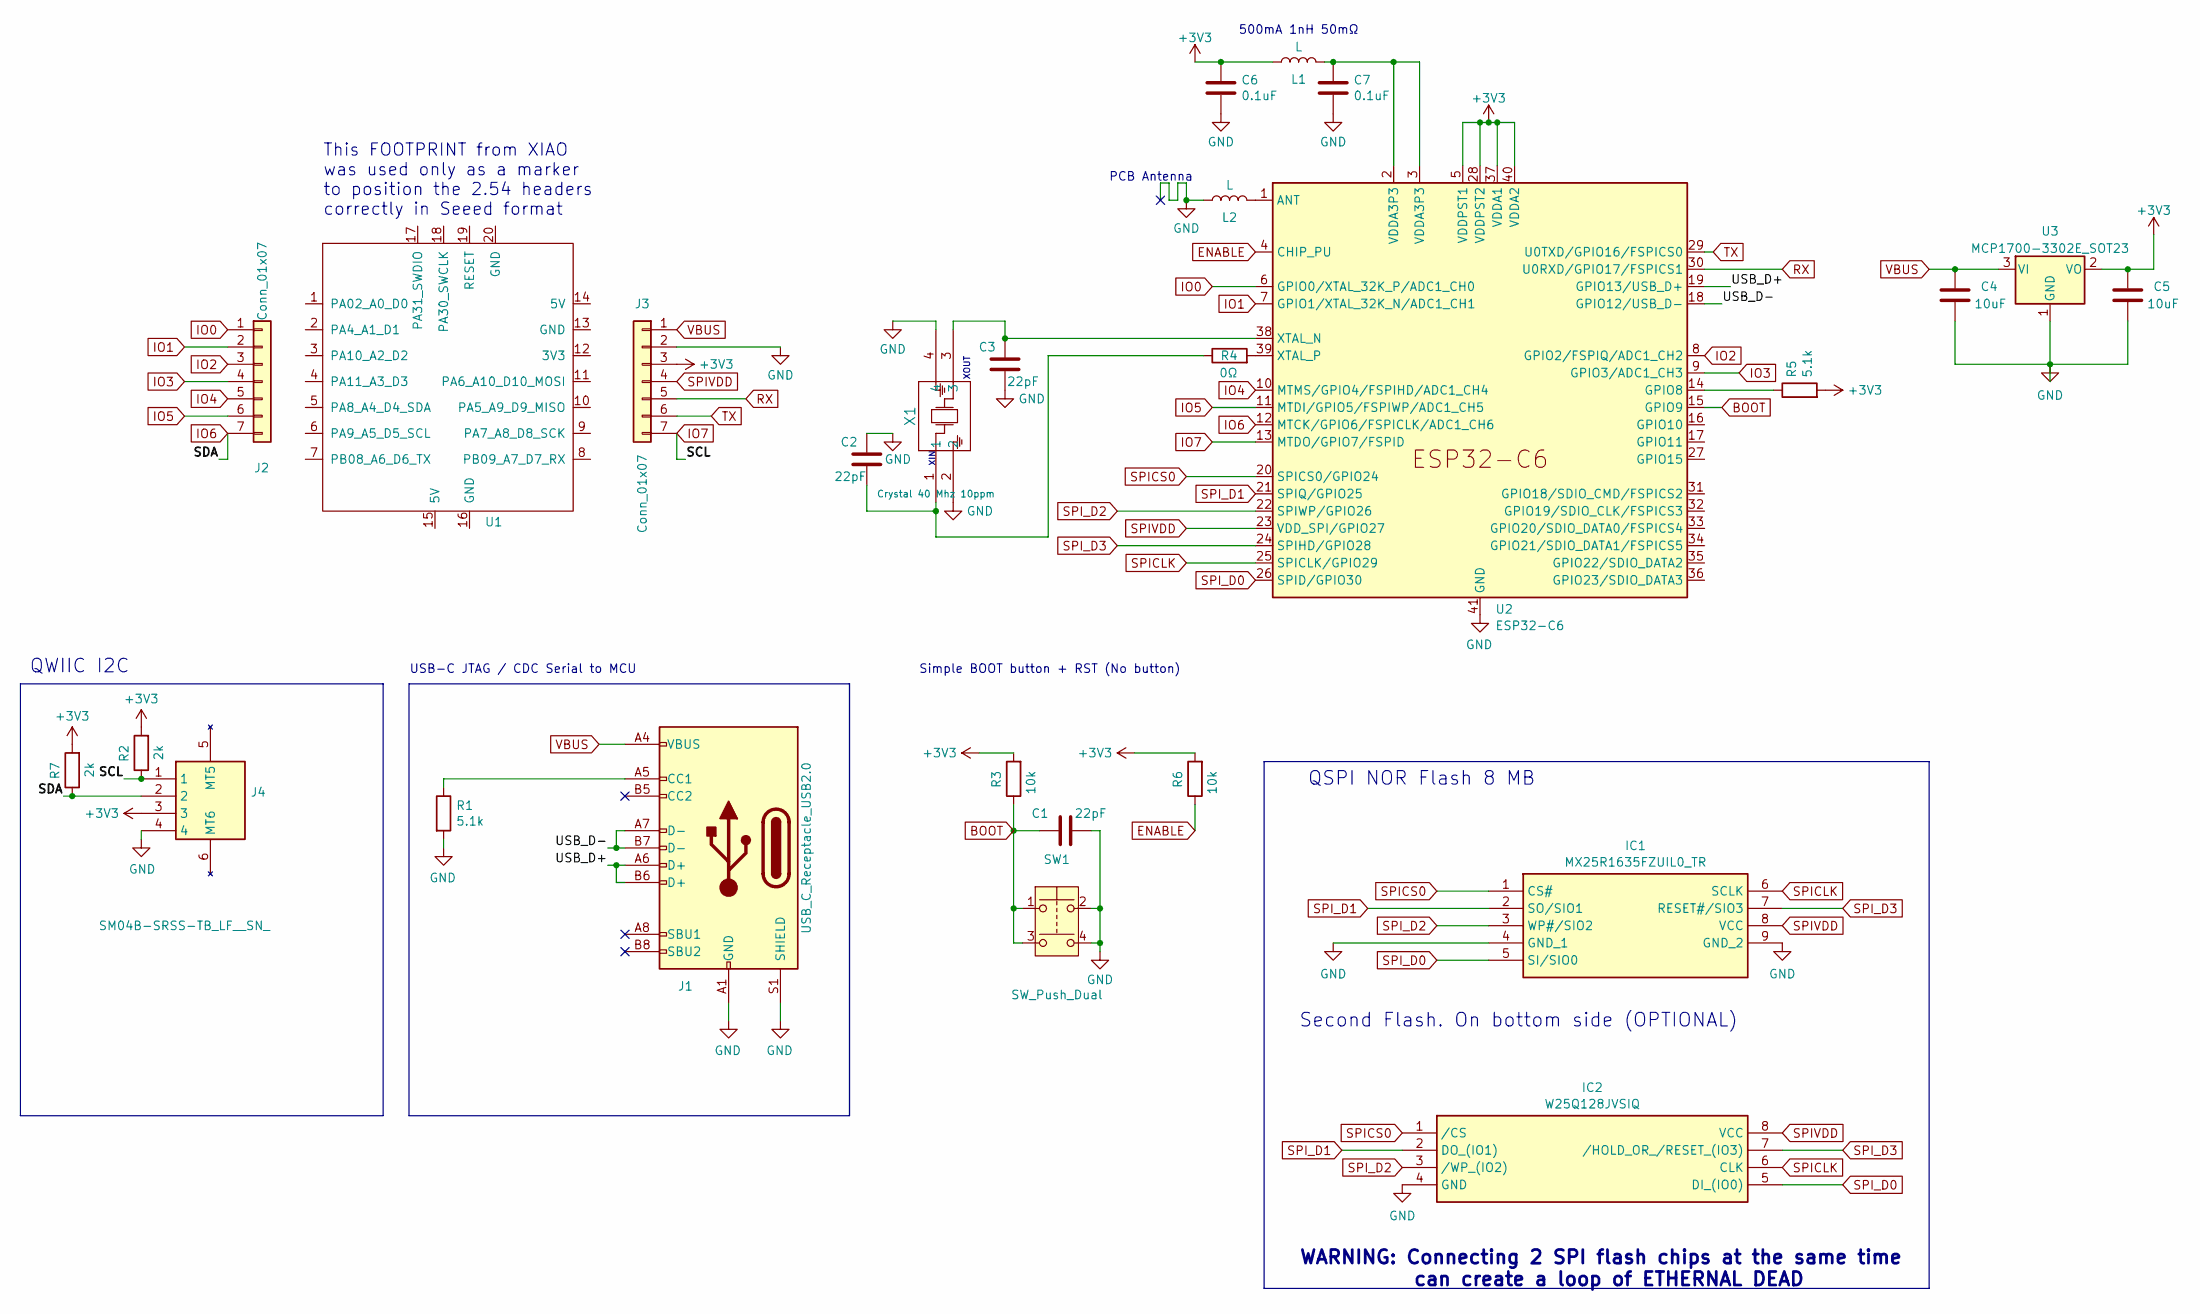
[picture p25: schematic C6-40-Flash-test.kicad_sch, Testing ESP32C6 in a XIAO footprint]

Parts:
C1, C2, C3: 22pF; C_0402_1005Metric; LCSC C5119318
C4, C5: 10uF; C_0805_2012Metric; LCSC C15850
C6, C7: 0.1uF; C_0603_1608Metric; LCSC C327087
IC1: MX25R1635FZUIL0_TR; MX25R1635FZUIL0TR; LCSC C152595
IC2: W25Q128JVSIQ; SOIC127P790X216-8N; Manufacturer_Part_Number W25Q128JVSIQ; Mouser Part Number 454-W25Q128JVSIQ
J1: USB_C_Receptacle_USB2.0; USB_C_Receptacle_HRO_TYPE-C-31-M-12; LCSC C165948
J2, J3: Conn_01x07; PinSocket_1x07_P2.54mm_Vertical
J4: SM04B-SRSS-TB_LF__SN_; QWIIC_SM04B-SRSS-TB_LFSN_; Manufacturer_Part_Number SM04B-SRSS-TB(LF)(SN); LCSC C160404
L1: L; L_0603_1608Metric; LCSC C1027
L2: L; L_0603_1608Metric; LCSC C5252358
R1, R5: 5.1k; R_0603_1608Metric; LCSC C23186
R2, R7: 2k; R_0402_1005Metric; LCSC C4109
R3, R6: 10k; R_0402_1005Metric; LCSC C4322213
R4: 0Ω; R_0603_1608Metric; LCSC C21189
SW1: SW_Push_Dual; switch_SKSVCCE010; LCSC C325005
U1: SeeeduinoXIAO; Seeeduino XIAO-MOUDLE14P-2.54-21X17.8MM
U2: ESP32-C6; QFN-40-1EP_5x5mm_P0.4mm_EP3.6x3.6mm; LCSC C5364646
U3: MCP1700-3302E_SOT23; SOT-23; LCSC C39051
X1: Crystal 40 Mhz 10ppm; Crystal_ECS-40Mhz_ECS; LCSC C555614

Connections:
+3V3: C5.1, C6.2, J3.3, J4.3, L1.1, R2.2, R3.2, R5.2, R6.2, R7.2, U2.5 (VDDPST1), U2.28 (VDDPST2), U2.37 (VDDA1), U2.40 (VDDA2), U3.2 (VO)
/USB_D+: J1.A6 (D+), J1.B6 (D+), U2.19 (GPIO13/USB_D+)
/USB_D-: J1.A7 (D-), J1.B7 (D-), U2.18 (GPIO12/USB_D-)
BOOT: C1.1, R3.1, SW1.1, SW1.3, U2.15 (GPIO9)
ENABLE: R6.1, U2.4 (CHIP_PU)
GND: C1.2, C2.1, C3.2, C4.2, C5.2, C6.1, C7.1, IC1.4 (GND_1), IC1.9 (GND_2), IC2.4 (GND), J1.A1 (GND), J1.A12 (GND), J1.B1 (GND), J1.B12 (GND), J1.S1 (SHIELD), J3.2, J4.4, L2.1, R1.2, SW1.2, SW1.4, U2.41 (GND), U3.1 (GND), X1.2, X1.4
IO0: J2.1, U2.6 (GPIO0/XTAL_32K_P/ADC1_CH0)
IO1: J2.2, U2.7 (GPIO1/XTAL_32K_N/ADC1_CH1)
IO2: J2.3, U2.8 (GPIO2/FSPIQ/ADC1_CH2)
IO3: J2.4, U2.9 (GPIO3/ADC1_CH3)
IO4: J2.5, U2.10 (MTMS/GPIO4/FSPIHD/ADC1_CH4)
IO5: J2.6, U2.11 (MTDI/GPIO5/FSPIWP/ADC1_CH5)
IO6: J2.7, J4.2, R7.1, U2.12 (MTCK/GPIO6/FSPICLK/ADC1_CH6)
IO7: J3.7, J4.1, R2.1, U2.13 (MTDO/GPIO7/FSPID)
unnamed: C2.2, R4.1, X1.1
unnamed: C7.2, L1.2, U2.2 (VDDA3P3), U2.3 (VDDA3P3)
unnamed: J1.A5 (CC1), R1.1
unnamed: L2.2, U2.1 (ANT)
unnamed: R5.1, U2.14 (GPIO8)
unnamed: C3.1, U2.38 (XTAL_N), X1.3
unnamed: R4.2, U2.39 (XTAL_P)
RX: J3.5, U2.30 (U0RXD/GPIO17/FSPICS1)
SPICLK: IC1.6 (SCLK), IC2.6 (CLK), U2.25 (SPICLK/GPIO29)
SPICS0: IC1.1 (CS#), IC2.1 (/CS), U2.20 (SPICS0/GPIO24)
SPIVDD: IC1.8 (VCC), IC2.8 (VCC), J3.4, U2.23 (VDD_SPI/GPIO27)
SPI_D0: IC1.5 (SI/SIO0), IC2.5 (DI_(IO0)), U2.26 (SPID/GPIO30)
SPI_D1: IC1.2 (SO/SIO1), IC2.2 (DO_(IO1)), U2.21 (SPIQ/GPIO25)
SPI_D2: IC1.3 (WP#/SIO2), IC2.3 (/WP_(IO2)), U2.22 (SPIWP/GPIO26)
SPI_D3: IC1.7 (RESET#/SIO3), IC2.7 (/HOLD_OR_/RESET_(IO3)), U2.24 (SPIHD/GPIO28)
TX: J3.6, U2.29 (U0TXD/GPIO16/FSPICS0)
VBUS: C4.1, J1.A4 (VBUS), J1.A9 (VBUS), J1.B4 (VBUS), J1.B9 (VBUS), J3.1, U3.3 (VI)

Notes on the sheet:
QSPI NOR Flash 8 MB
Second Flash. On bottom side (OPTIONAL)
XOUT
USB-C JTAG / CDC Serial to MCU
Simple BOOT button + RST (No button)
WARNING: Connecting 2 SPI flash chips at the same time can create a loop of ETHERNAL DEAD
This FOOTPRINT from XIAO was used only as a marker to position the 2.54 headers correctly in Seeed format
PCB Antenna
XIN
QWIIC I2C
500mA 1nH 50mΩ

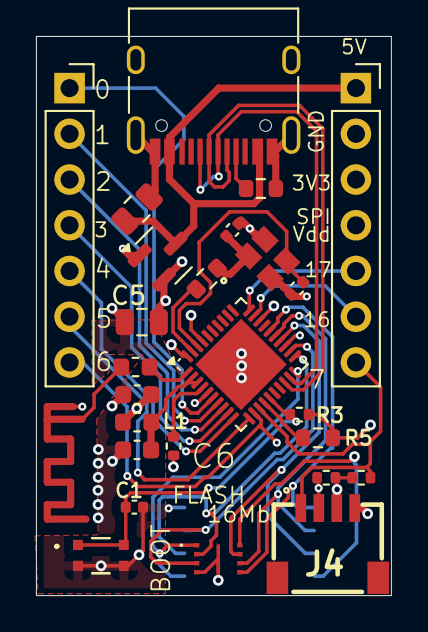
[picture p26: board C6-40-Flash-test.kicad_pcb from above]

Board: 4 copper layers, 19.7 x 31.1 mm, 26 parts (1 on the bottom side), 31 nets.

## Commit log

2024-09-13 First version passing DRC
    [H-C6-ulp.kicad_pcb, H-C6-ulp.kicad_sch, JST_SM02B-SRSS-TB__LF__SN.stp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]
2024-09-13 Add QWIIC I2c connector
    [H-C6-ulp.kicad_pcb, H-C6-ulp.kicad_sch, L-40xx.stp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]
2024-09-15 Rev 1.0 is quite ready for last review @bitbank2
    [H-C6-ulp.kicad_pcb, H-C6-ulp.kicad_sch, S2B-PH-SM4-TB_LF__SN_.stp]
2024-09-15 Move mounting H out of display area
    [H-C6-ulp.kicad_pcb]
2024-09-15 Add BOOT & RST switches
    [H-C6-ulp.kicad_pcb, H-C6-ulp.kicad_sch, switch_SKSVCCE010.stp]
2024-09-15 3 buttons, a bit risky routing
    [H-C6-ulp.kicad_pcb, H-C6-ulp.kicad_sch, KEY-SMD_L4.0-W2.9-H1.6-P3.75.step]
2024-09-16 Add Readme
    [H-C6-ulp.kicad_pcb, H-C6-ulp.kicad_sch]
2024-09-16 Add pull-ups
    [H-C6-ulp.kicad_pcb, H-C6-ulp.kicad_sch]
2024-09-16 Update L2 with same inductor 470nH than XIAO C6
    [H-C6-ulp.kicad_pcb, H-C6-ulp.kicad_sch, IND-SMD_L2.5-W2.0-H1.2_SPH252012.step]
2024-09-17 Add superCAP as RTC backup
    [H-C6-ulp.kicad_pcb, H-C6-ulp.kicad_sch, SuperCAP_XH414HG-IV01E.stp]
2024-09-17 Fix #2 Thanks @Uspizig
    [H-C6-ulp.kicad_pcb]
2024-09-24 Add 1mm TP for coin battery (Passes through regulator also)
    [H-C6-ulp.kicad_pcb, H-C6-ulp.kicad_sch]
2024-10-23 Add QSPI Flash
    [H-C6-ulp.kicad_pcb, H-C6-ulp.kicad_sch, W25Q80DVSSIG_FLASH.stp]
2024-10-23 Flash oh oh! Master of the universe
    [H-C6-ulp.kicad_pcb]
2024-10-23 Update Rev 1.1
    [H-C6-ulp.kicad_pcb]
2024-10-24 Add small XIAO format C6 tester w/FLASH
    [C6-40-Flash-test.kicad_pcb, C6-40-Flash-test.kicad_sch, xiao-clean.stl]
2024-10-24 Make antenna better (Is a shoelace)
    [ANTENNA - MIFA_TYPEB.dxf, C6-40-Flash-test.kicad_pcb, C6-40-Flash-test.kicad_sch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]
2024-10-24 C6 test new Flash
    [AT25SF041-XMHD-T_flash.stp, C6-40-Flash-test.kicad_pcb, C6-40-Flash-test.kicad_sch]
2024-11-12 Test with external flash
    [AT25SF041-XMHD-T_flash.stp, BOM.xlsx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]
2024-11-23 1.1 ready for review
    [ESP32-C6FH4.stp, H-C6-ulp.kicad_pcb, H-C6-ulp.kicad_sch]
2024-11-25 Saving 1.1 state before making it 51 mm
    [H-C6-ulp.kicad_pcb]
2024-11-26 Rel 1.1 ready
    [BOM.xlsx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]
2024-12-13 Fix epaper power
    [H-C6-ulp.kicad_pcb, H-C6-ulp.kicad_sch]
2024-12-16 Update Schematic

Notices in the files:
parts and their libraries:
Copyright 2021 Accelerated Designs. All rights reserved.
